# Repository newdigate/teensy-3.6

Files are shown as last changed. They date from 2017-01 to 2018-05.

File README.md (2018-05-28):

# Teensy 3.6 audio display projects

I'd like to explore whats possible with a teensy 3.6, the sgtl5000 audioboard, and an ILI9341 tft display board;
* https://www.pjrc.com/teensy/index.html
* https://www.pjrc.com/store/teensy3_audio.html
* https://www.pjrc.com/store/display_ili9341.html

I have a little bit of electrical engineering knowledge but I don't have alot of practical experience. I am a software engineer by trade and Im interested in audio applications of the teensy devices; 

I've wired the three components together using breadboard and jumper wires. Although it does work intermittently, the digital i2s audio connection is very fragile and mostly results in heavy digital distorion. I've tried to rule out all the obvious potential faults - swapped teensy mainboards, swapped audioboards, swapped different versions of teensy devices... the problem seems to be with my breadboard, or the jumper wires. I need to check it out with a decent oscilliscope. So I've decided to build a custom PCB. I think this should solve my distortion issue.    

[some things I learned about Fritzing](https://github.com/newdigate/teensy-3.6/tree/master/fritzing)

### About Teensy:
Teensy is an awesome microcontroller development kit from pjrc.com http://www.pjrc.com/teensy/index.html

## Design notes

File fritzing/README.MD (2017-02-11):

### Some things I learned about Fritzing
A few months ago I started noticing some really nice diagrams (mostly arduino) while searching for pull-up resistor solutions for arduino. I was curious about how people were creating these nice breadboard diagrams (I love a diagram). I discovered Fritzing this way. 

When I started this project a week or two ago, I thought it would be good to use Fritzing to build the PCB, since the custom parts for previous teensy models already exist in fritzing. My first step was to build svg files for breadboard view, schematic view and pcb view for fritzing. This was my first pcb project, ever. 

Now that I've made a couple of iterations of my first custom fritzing part, I've learned a few things. 
  * Fritzing makes really nice visual diagrams of breadboards.
  * It has a decent collection of components.
  * It is a great platform for teachers, students and enthusiasts. 
  * Making a custom parts for the first time is pretty tough. But all the information is out there.  
  * When creating custom parts, it crashes (esp. when you're learning fritzing svg integration). Work must be saved frequently;    
  * The documentation on making custom parts is a little out dated.
  * Autorouting is not usable (schematic, or pcb).
  * It is not practical to build a PCB in fritzing. Unfortunately. 
  
Having learnt these things I am glad there is a teensy 3.6 component for fritzing.

I have also decided to go forward using Eagle to create PCBs and Fritzing to create sweet breadboard diagrams. 

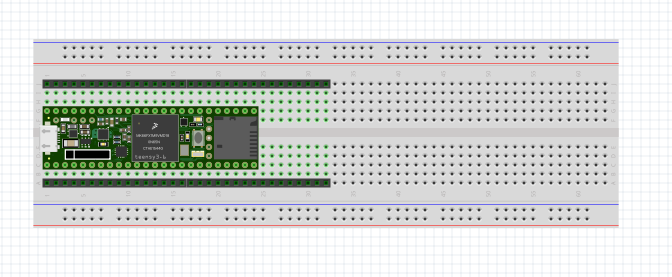
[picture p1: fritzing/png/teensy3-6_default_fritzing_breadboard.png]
teensy breadboard view teensy 3.6 pcb for fritzing


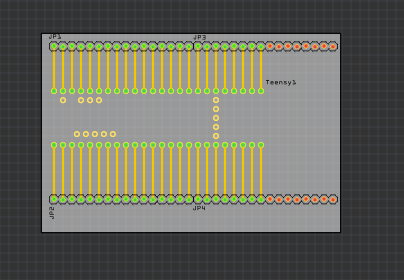
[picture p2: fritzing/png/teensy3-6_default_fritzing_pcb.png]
teensy pcb view teensy 3.6 pcb for fritzing


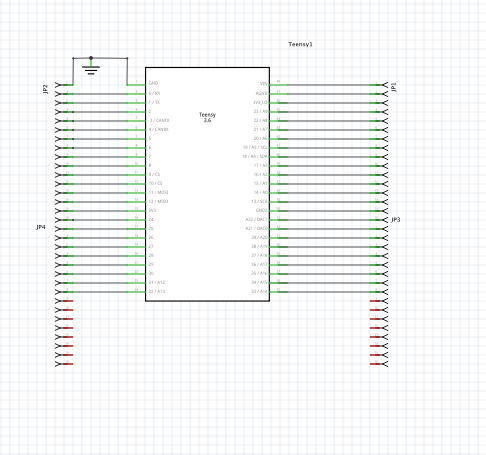
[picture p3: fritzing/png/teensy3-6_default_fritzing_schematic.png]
teensy schematic view teensy 3.6 pcb for fritzing


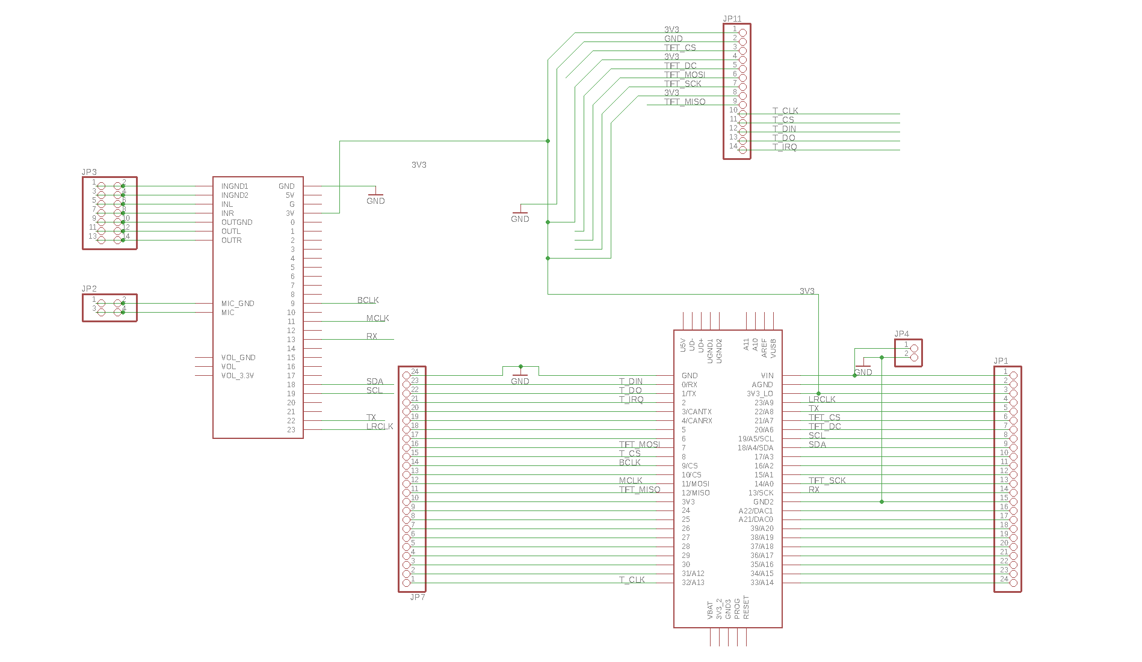
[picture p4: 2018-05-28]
audio-board-tft/images/teensy-3.6-audio-tft.png

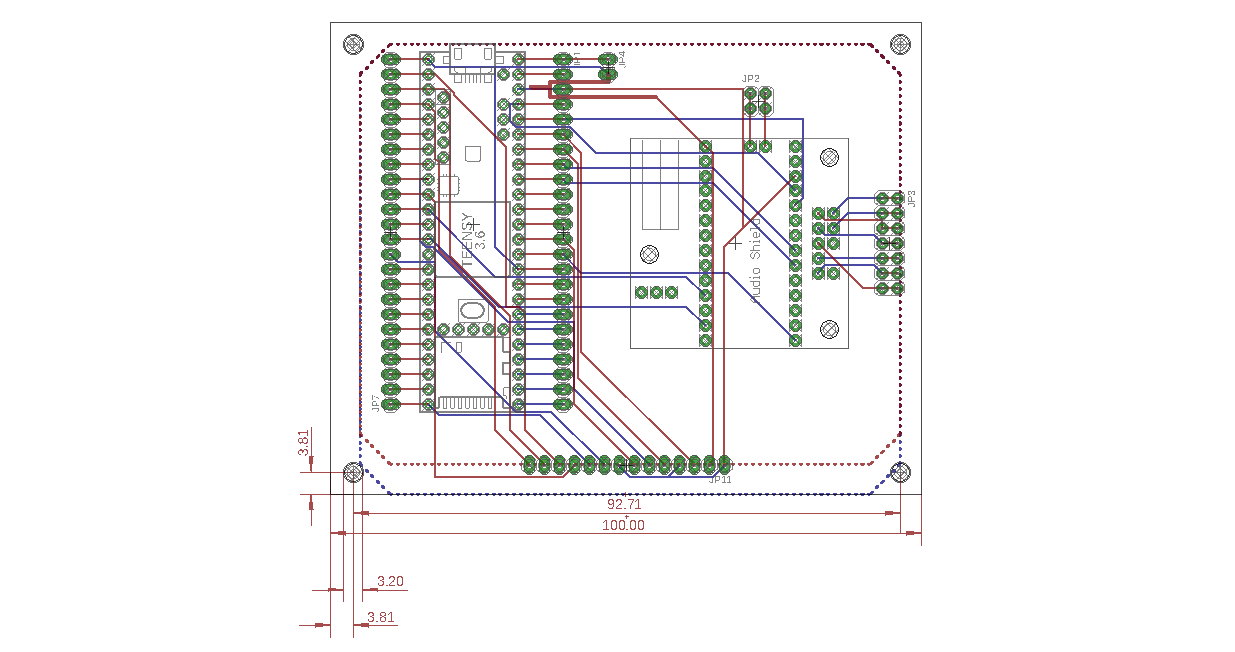
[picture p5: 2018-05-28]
audio-board-tft/images/teensy-3.6-audio-tft-pcb.png

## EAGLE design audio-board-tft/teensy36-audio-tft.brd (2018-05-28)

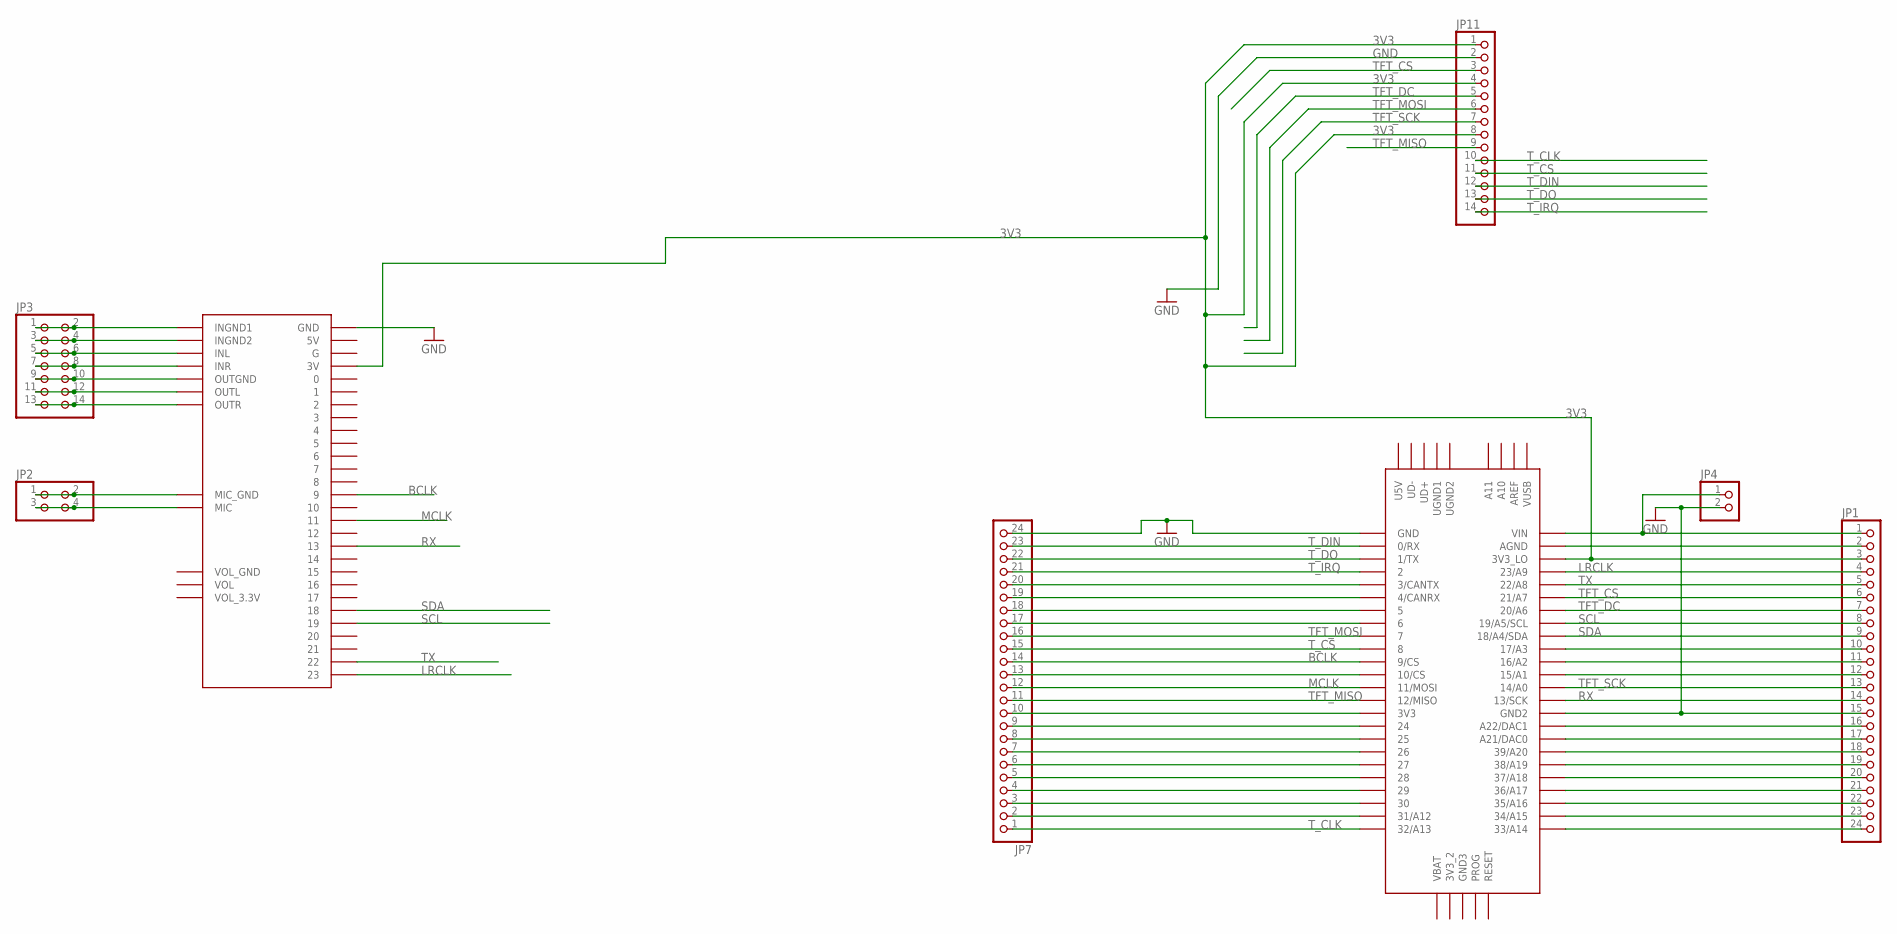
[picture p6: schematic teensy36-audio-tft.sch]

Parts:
JP1, JP7: PINHD-1X24; 1X24
JP2: PINHD-2X2; 2X02
JP3: PINHD-2X7; 2X07
JP4: PINHD-1X2; 1X02
JP11: PINHD-1X14; 1X14
U$2: AUDIOSHIELD
U$3: TEENSY_3.5/3.6

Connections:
3V3: JP1.3, JP11.1, JP11.4, JP11.8, U$2.3V, U$3.3V3_LO
BCLK: JP7.14, U$2.9, U$3.9/CS
GND: JP1.15, JP4.2, JP7.24, JP11.2, U$2.GND, U$3.GND, U$3.GND2
LRCLK: JP1.4, U$2.23, U$3.23/A9
MCLK: JP7.12, U$2.11, U$3.11/MOSI
unnamed: JP2.1, JP2.2, U$2.GND_MIC (MIC_GND)
unnamed: JP1.1, JP4.1, U$3.VIN
unnamed: JP7.20, U$3.3/CANTX
unnamed: JP7.19, U$3.4/CANRX
unnamed: JP7.18, U$3.5
unnamed: JP2.3, JP2.4, U$2.MIC
unnamed: JP3.1, JP3.2, U$2.INGND1
unnamed: JP3.3, JP3.4, U$2.INGND2
unnamed: JP3.5, JP3.6, U$2.INL
unnamed: JP3.7, JP3.8, U$2.INR
unnamed: JP3.9, JP3.10, U$2.OUTGND
unnamed: JP3.11, JP3.12, U$2.OUTL
unnamed: JP3.13, JP3.14, U$2.OUTR
unnamed: JP7.17, U$3.6
unnamed: JP7.13, U$3.10/CS
unnamed: JP7.10, U$3.3V3
unnamed: JP7.9, U$3.24
unnamed: JP7.8, U$3.25
unnamed: JP7.7, U$3.26
unnamed: JP7.6, U$3.27
unnamed: JP7.5, U$3.28
unnamed: JP7.4, U$3.29
unnamed: JP7.3, U$3.30
unnamed: JP7.2, U$3.31/A12
unnamed: JP1.2, U$3.AGND
unnamed: JP1.10, U$3.17/A3
unnamed: JP1.11, U$3.16/A2
unnamed: JP1.12, U$3.15/A1
unnamed: JP1.16, U$3.A22/DAC1
unnamed: JP1.17, U$3.21/DAC0 (A21/DAC0)
unnamed: JP1.18, U$3.39/A20
unnamed: JP1.19, U$3.38/A19
unnamed: JP1.20, U$3.37/A18
unnamed: JP1.21, U$3.36/A17
unnamed: JP1.22, U$3.35/A16
unnamed: JP1.23, U$3.34/A15
unnamed: JP1.24, U$3.33/A14
RX: JP1.14, U$2.13, U$3.13/SCK
SCL: JP1.8, U$2.19, U$3.19/A5/SCL
SDA: JP1.9, U$2.18, U$3.18/A4/SDA
TFT_CS: JP1.6, JP11.3, U$3.21/A7
TFT_DC: JP1.7, JP11.5, U$3.20/A6
TFT_MISO: JP7.11, JP11.9
TFT_MOSI: JP7.16, JP11.6, U$3.7
TFT_SCK: JP1.13, JP11.7, U$3.14/A0
TX: JP1.5, U$2.22, U$3.22/A8
T_CLK: JP7.1, JP11.10, U$3.32/A13
T_CS: JP7.15, JP11.11, U$3.8
T_DIN: JP7.23, JP11.12, U$3.0/RX
T_DO: JP7.22, JP11.13, U$3.1/TX
T_IRQ: JP7.21, JP11.14, U$3.2

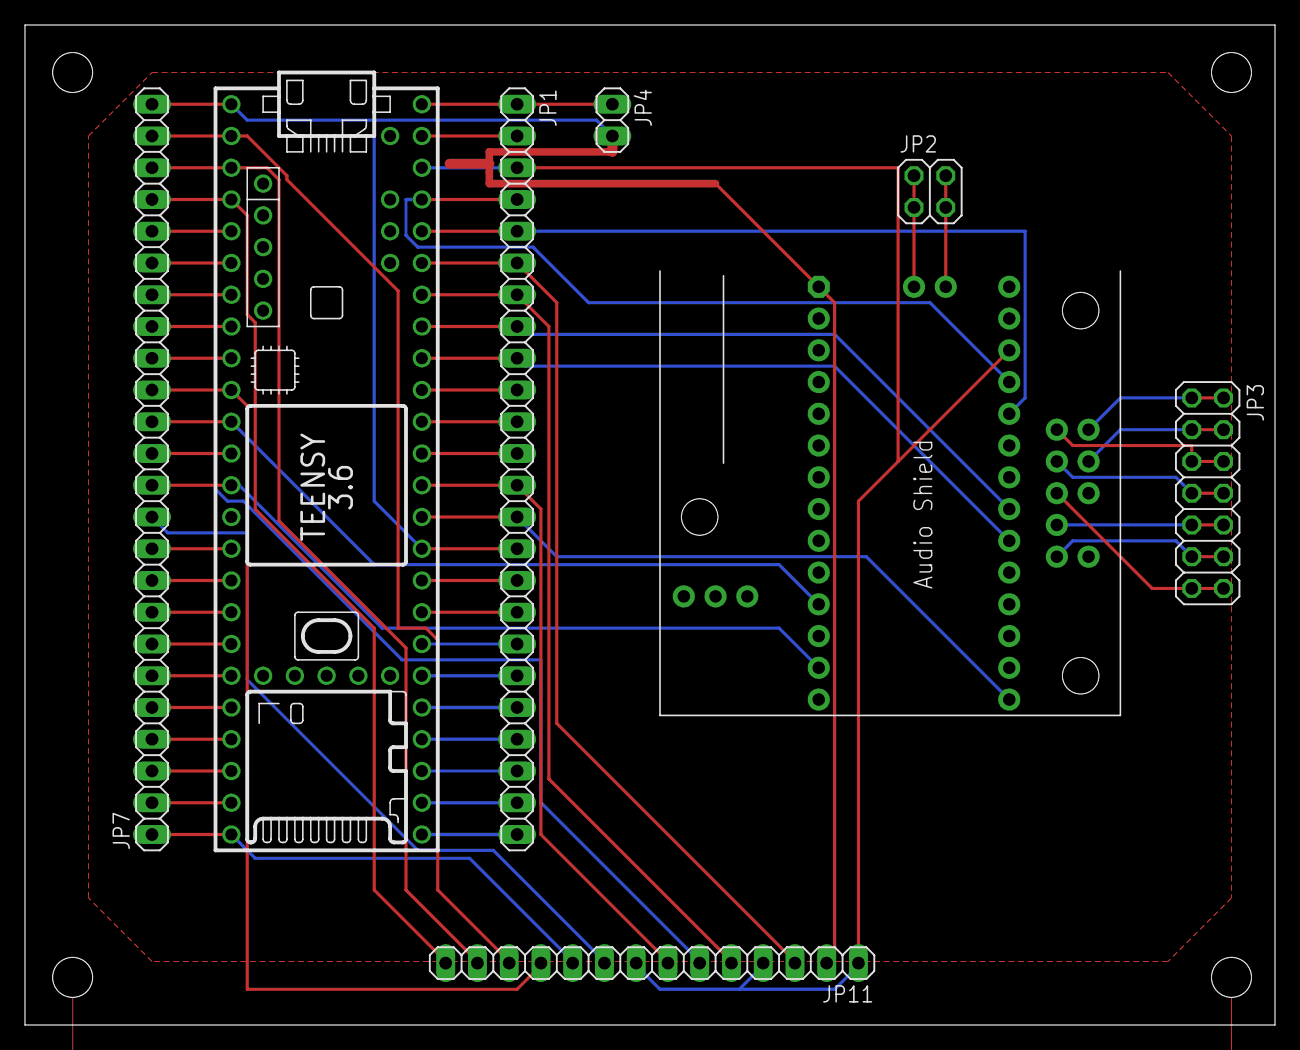
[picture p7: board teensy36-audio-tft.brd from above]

Board: 2 copper layers, 100.0 x 80.0 mm, 8 parts (0 on the bottom side), 56 nets.

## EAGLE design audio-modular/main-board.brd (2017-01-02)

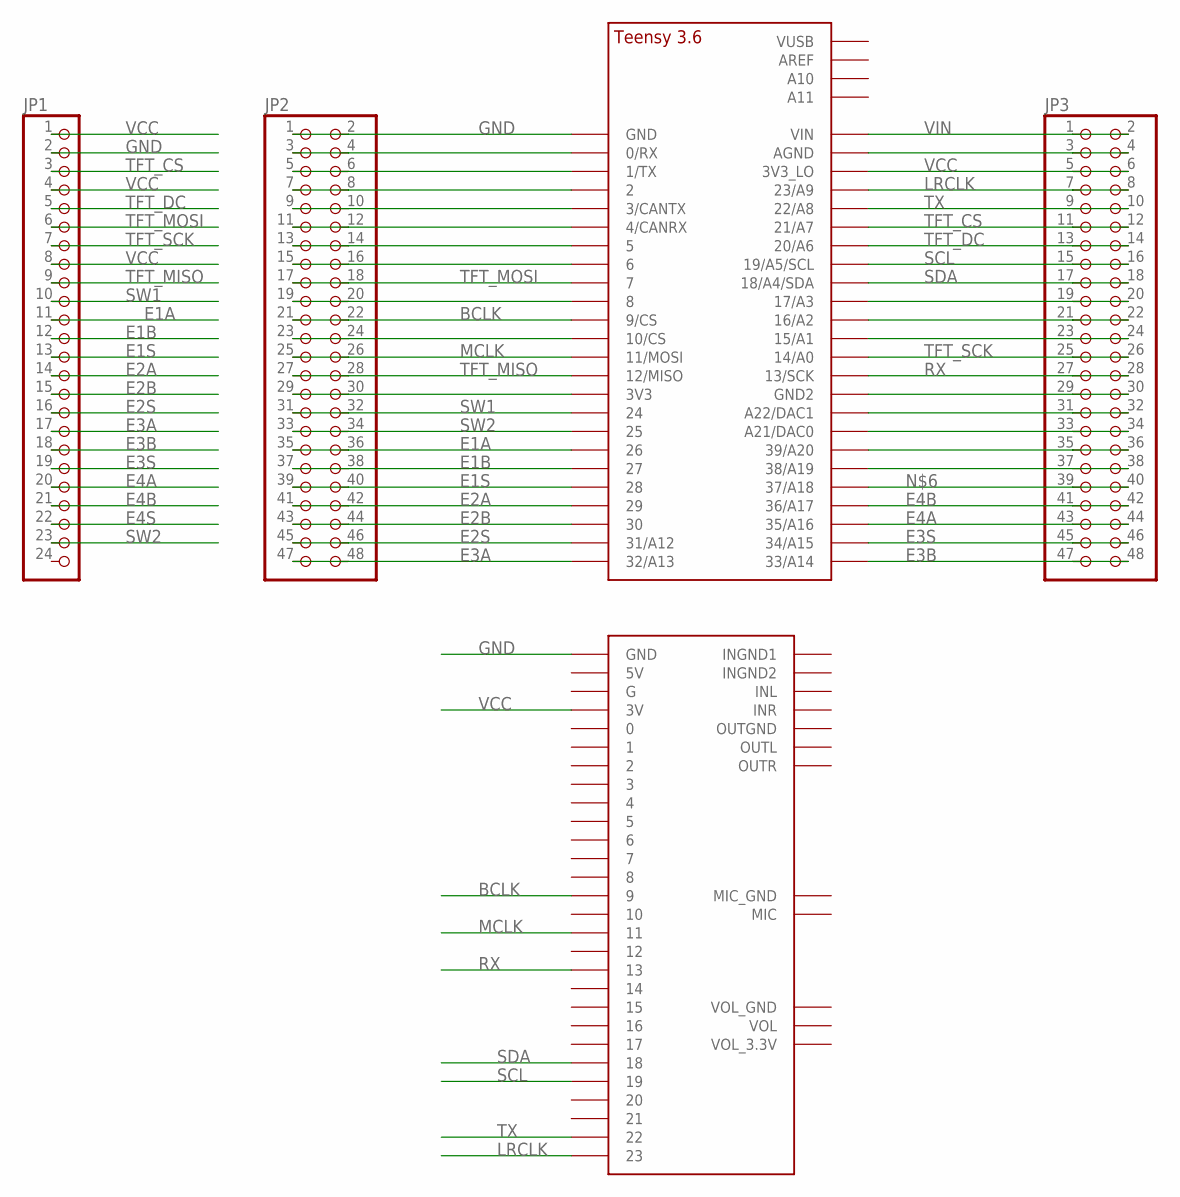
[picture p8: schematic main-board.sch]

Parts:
JP1: PINHD-1X24; 1X24
JP2, JP3: PINHD-2X24; 2X24
U$1: TEENSY_3.5/3.6_BASIC
U$2: AUDIOSHIELD

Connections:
BCLK: JP2.21, JP2.22, U$1.9/CS, U$2.9
E1A: JP1.11, JP2.35, JP2.36, U$1.26
E1B: JP1.12, JP2.37, JP2.38, U$1.27
E1S: JP1.13, JP2.39, JP2.40, U$1.28
E2A: JP1.14, JP2.41, JP2.42, U$1.29
E2B: JP1.15, JP2.43, JP2.44, U$1.30
E2S: JP1.16, JP2.45, JP2.46, U$1.31/A12
E3A: JP1.17, JP2.47, JP2.48, U$1.32/A13
E3B: JP1.18, JP3.47, JP3.48, U$1.33/A14
E3S: JP1.19, JP3.45, JP3.46, U$1.34/A15
E4A: JP1.20, JP3.43, JP3.44, U$1.35/A16
E4B: JP1.21, JP3.41, JP3.42, U$1.36/A17
E4S: JP1.22
GND: JP1.2, JP2.1, JP2.2, U$1.GND, U$2.GND
LRCLK: JP3.7, JP3.8, U$1.23/A9, U$2.23
MCLK: JP2.25, JP2.26, U$1.11/MOSI, U$2.11
unnamed: JP2.3, JP2.4, U$1.0/RX
unnamed: JP2.5, JP2.6, U$1.1/TX
unnamed: JP2.7, JP2.8, U$1.2
unnamed: JP3.39, JP3.40, U$1.37/A18
unnamed: JP2.9, JP2.10, U$1.3/CANTX
unnamed: JP2.11, JP2.12, U$1.4/CANRX
unnamed: JP2.13, JP2.14, U$1.5
unnamed: JP2.15, JP2.16, U$1.6
unnamed: JP2.19, JP2.20, U$1.8
unnamed: JP2.23, JP2.24, U$1.10/CS
unnamed: JP2.29, JP2.30, U$1.3V3
unnamed: JP3.3, JP3.4, U$1.AGND
unnamed: JP3.19, JP3.20, U$1.17/A3
unnamed: JP3.21, JP3.22, U$1.16/A2
unnamed: JP3.23, JP3.24, U$1.15/A1
unnamed: JP3.29, JP3.30, U$1.GND2
unnamed: JP3.31, JP3.32, U$1.A22/DAC1
unnamed: JP3.33, JP3.34, U$1.21/DAC0 (A21/DAC0)
unnamed: JP3.35, JP3.36, U$1.39/A20
unnamed: JP3.37, JP3.38, U$1.38/A19
RX: JP3.27, JP3.28, U$1.13/SCK, U$2.13
SCL: JP3.15, JP3.16, U$1.19/A5/SCL, U$2.19
SDA: JP3.17, JP3.18, U$1.18/A4/SDA, U$2.18
SW1: JP1.10, JP2.31, JP2.32, U$1.24
SW2: JP1.23, JP2.33, JP2.34, U$1.25
TFT_CS: JP1.3, JP3.11, JP3.12, U$1.21/A7
TFT_DC: JP1.5, JP3.13, JP3.14, U$1.20/A6
TFT_MISO: JP1.9, JP2.27, JP2.28, U$1.12/MISO
TFT_MOSI: JP1.6, JP2.17, JP2.18, U$1.7
TFT_SCK: JP1.7, JP3.25, JP3.26, U$1.14/A0
TX: JP3.9, JP3.10, U$1.22/A8, U$2.22
VCC: JP1.1, JP1.4, JP1.8, JP3.5, JP3.6, U$1.3V3_LO, U$2.3V
VIN: JP3.1, JP3.2, U$1.VIN

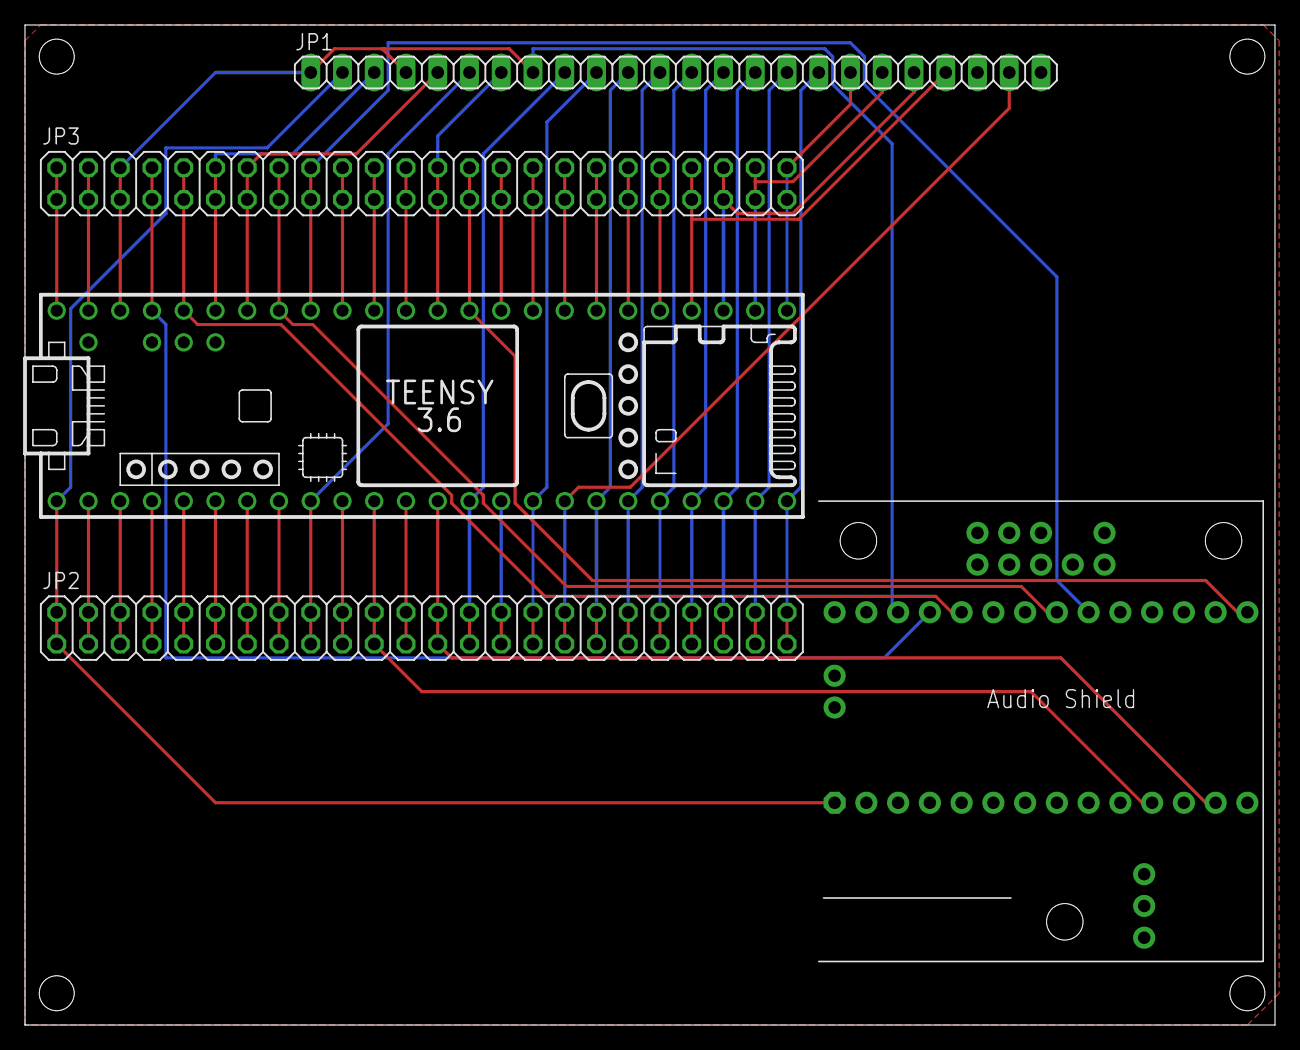
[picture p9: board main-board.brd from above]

Board: 2 copper layers, 100.0 x 80.0 mm, 5 parts (0 on the bottom side), 48 nets.

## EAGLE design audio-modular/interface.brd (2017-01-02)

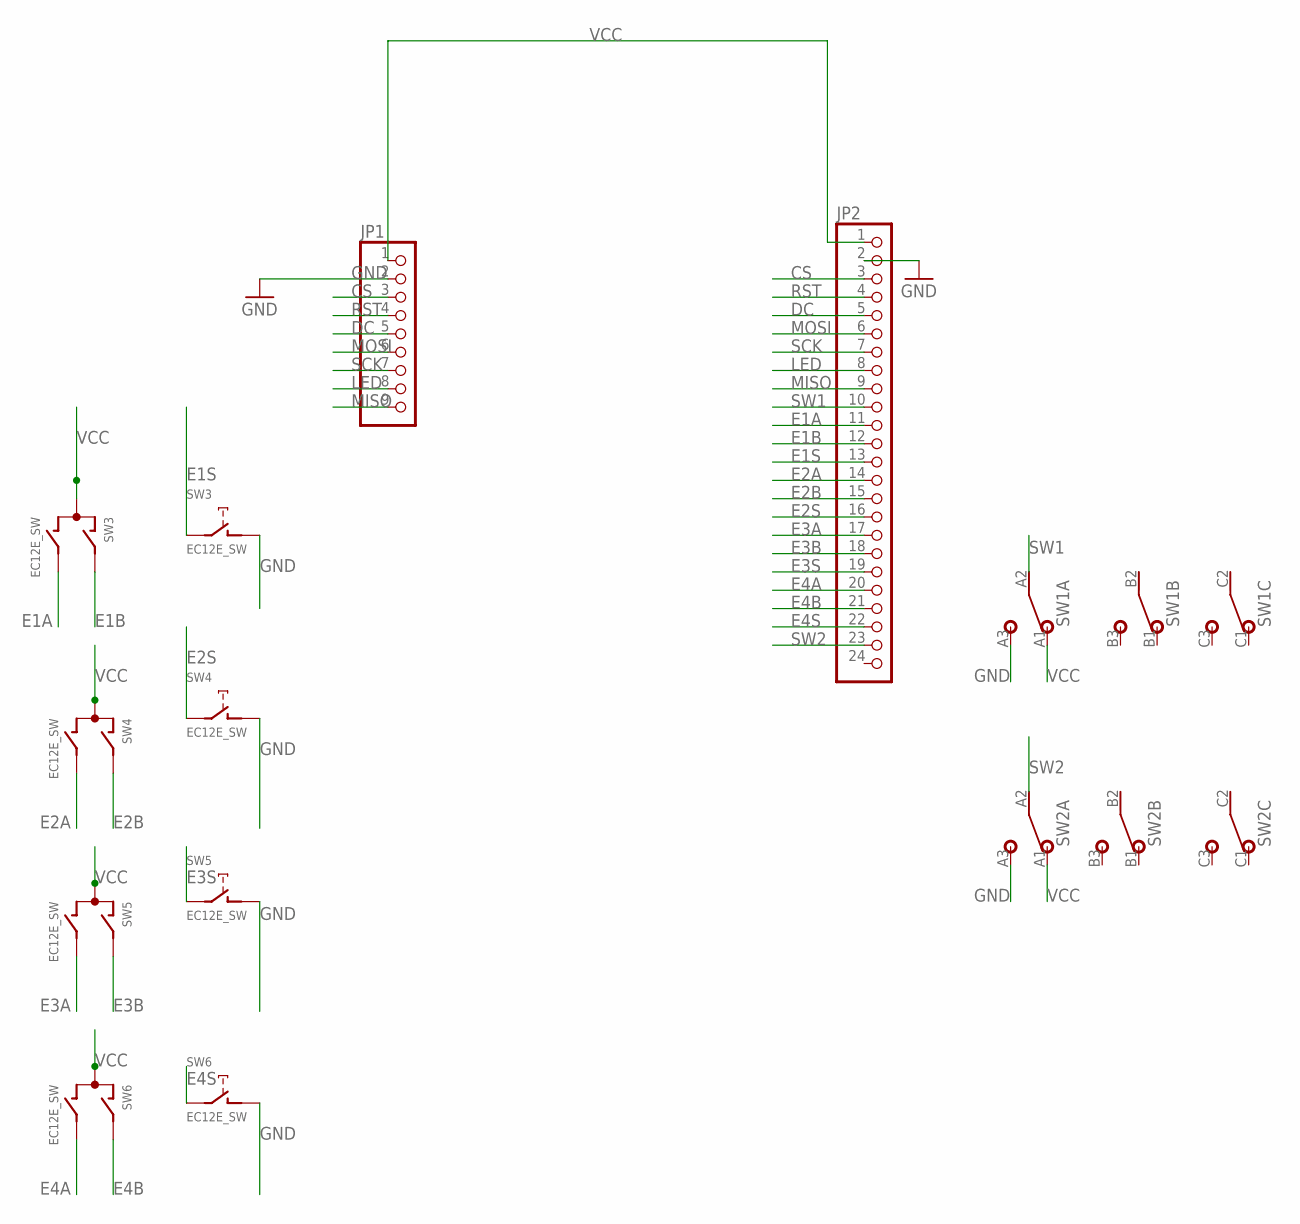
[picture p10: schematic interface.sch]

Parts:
JP1: PINHD-1X9; 1X09
JP2: PINHD-1X24; 1X24
SW1, SW2: 3PDTBLUE; CHINABLUE
SW3, SW4, SW5, SW6: EC12E_SW; ALPS_EC12E_SW

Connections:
CS: JP1.3, JP2.3
DC: JP1.5, JP2.5
E1A: JP2.11, SW3.B
E1B: JP2.12, SW3.A
E1S: JP2.13, SW3.E (2)
E2A: JP2.14, SW4.B
E2B: JP2.15, SW4.A
E2S: JP2.16, SW4.E (2)
E3A: JP2.17, SW5.B
E3B: JP2.18, SW5.A
E3S: JP2.19, SW5.E (2)
E4A: JP2.20, SW6.B
E4B: JP2.21, SW6.A
E4S: JP2.22, SW6.E (2)
GND: JP1.2, JP2.2, SW1.A3 (3), SW2.A3 (3), SW3.D (1), SW4.D (1), SW5.D (1), SW6.D (1)
LED: JP1.8, JP2.8
MISO: JP1.9, JP2.9
MOSI: JP1.6, JP2.6
RST: JP1.4, JP2.4
SCK: JP1.7, JP2.7
SW1: JP2.10, SW1.A2 (2)
SW2: JP2.23, SW2.A2 (2)
VCC: JP1.1, JP2.1, SW1.A1 (1), SW2.A1 (1), SW3.C, SW4.C, SW5.C, SW6.C

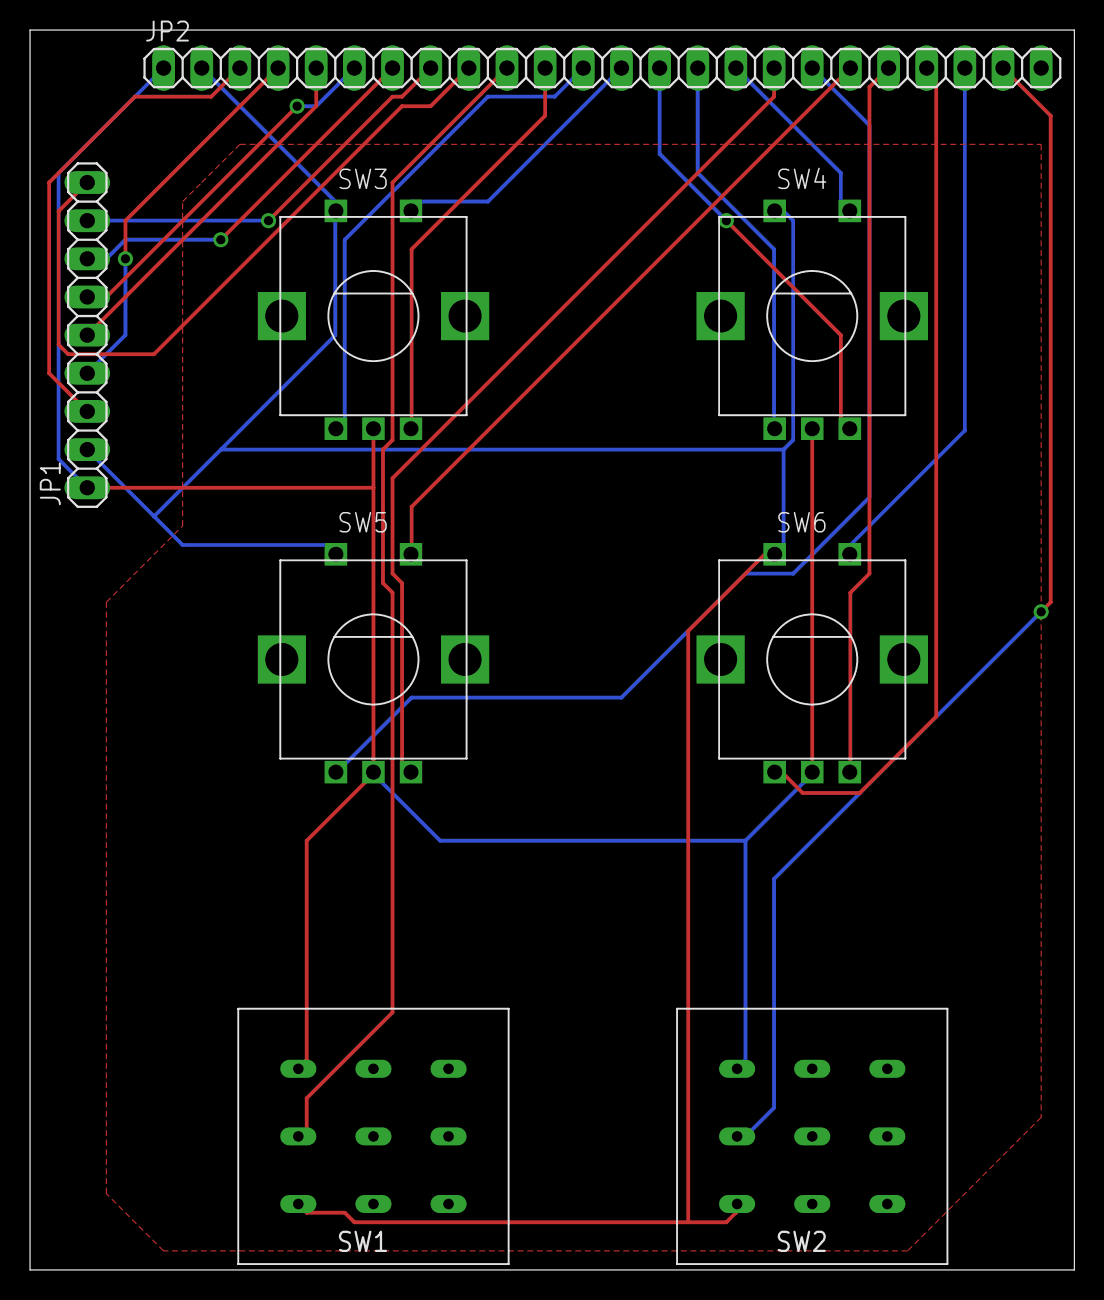
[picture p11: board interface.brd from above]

Board: 2 copper layers, 69.5 x 82.5 mm, 8 parts (0 on the bottom side), 23 nets.

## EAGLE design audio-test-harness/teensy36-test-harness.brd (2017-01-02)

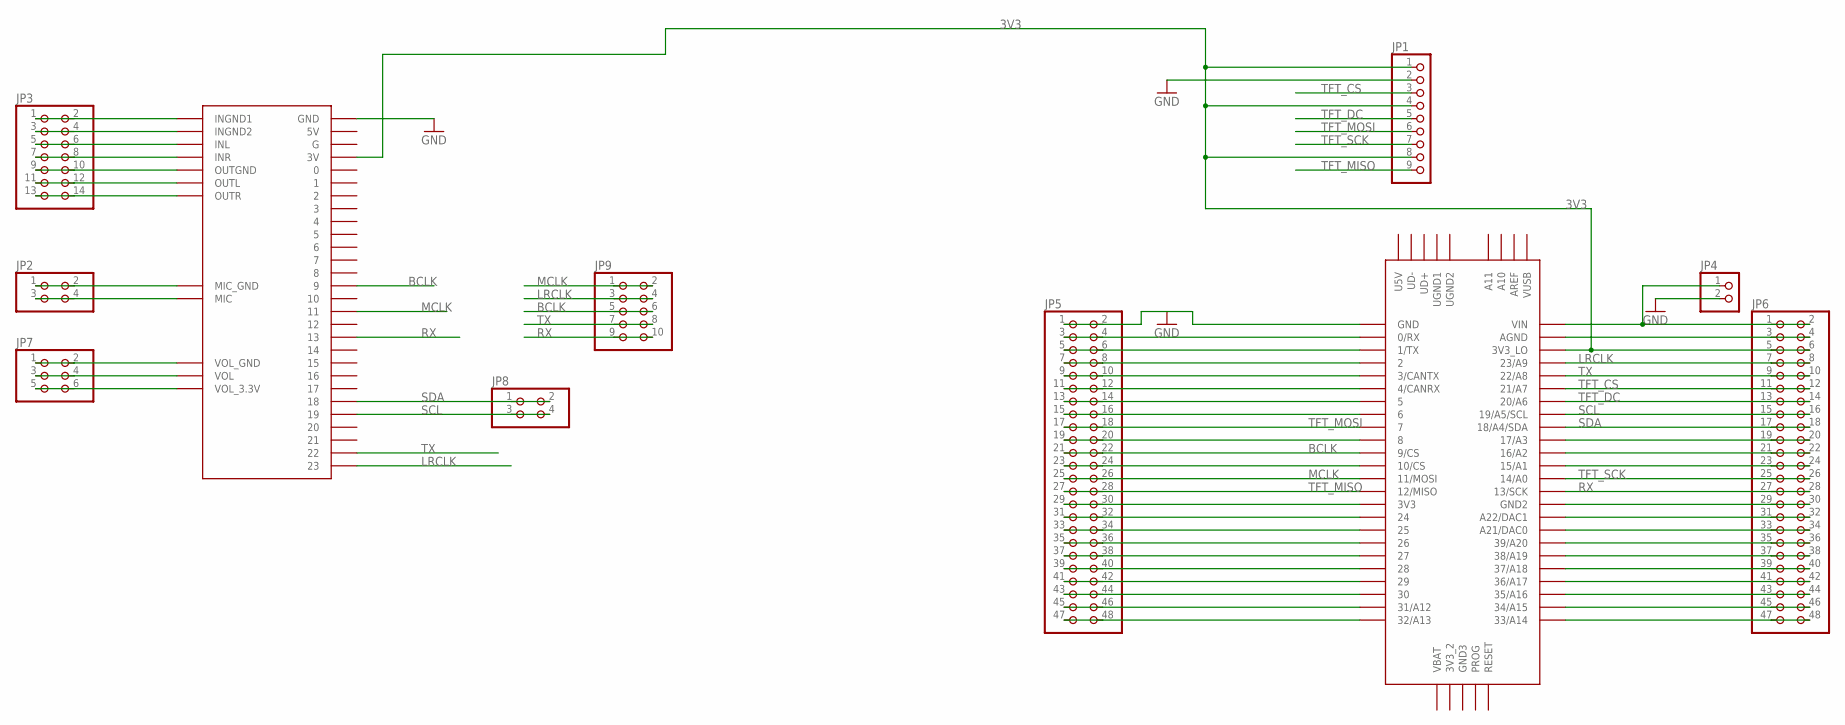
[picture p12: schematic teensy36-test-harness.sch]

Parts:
JP1: PINHD-1X9; 1X09
JP2, JP8: PINHD-2X2; 2X02
JP3: PINHD-2X7; 2X07
JP4: PINHD-1X2; 1X02
JP5, JP6: PINHD-2X24; 2X24
JP7: PINHD-2X3; 2X03
JP9: PINHD-2X5; 2X05
U$2: AUDIOSHIELD
U$3: TEENSY_3.5/3.6

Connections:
3V3: JP1.1, JP1.4, JP1.8, JP6.5, JP6.6, U$2.3V, U$3.3V3_LO
BCLK: JP5.21, JP5.22, JP9.5, JP9.6, U$2.9, U$3.9/CS
GND: JP1.2, JP4.2, JP5.1, JP5.2, U$2.GND, U$3.GND
LRCLK: JP6.7, JP6.8, JP9.3, JP9.4, U$2.23, U$3.23/A9
MCLK: JP5.25, JP5.26, JP9.1, JP9.2, U$2.11, U$3.11/MOSI
unnamed: JP2.1, JP2.2, U$2.GND_MIC (MIC_GND)
unnamed: JP4.1, JP6.1, JP6.2, U$3.VIN
unnamed: JP7.1, JP7.2, U$2.VOL_GND
unnamed: JP5.3, JP5.4, U$3.0/RX
unnamed: JP5.5, JP5.6, U$3.1/TX
unnamed: JP5.7, JP5.8, U$3.2
unnamed: JP5.9, JP5.10, U$3.3/CANTX
unnamed: JP5.11, JP5.12, U$3.4/CANRX
unnamed: JP5.13, JP5.14, U$3.5
unnamed: JP2.3, JP2.4, U$2.MIC
unnamed: JP3.1, JP3.2, U$2.INGND1
unnamed: JP3.3, JP3.4, U$2.INGND2
unnamed: JP3.5, JP3.6, U$2.INL
unnamed: JP3.7, JP3.8, U$2.INR
unnamed: JP3.9, JP3.10, U$2.OUTGND
unnamed: JP3.11, JP3.12, U$2.OUTL
unnamed: JP3.13, JP3.14, U$2.OUTR
unnamed: JP5.15, JP5.16, U$3.6
unnamed: JP7.3, JP7.4, U$2.VOL
unnamed: JP5.19, JP5.20, U$3.8
unnamed: JP7.5, JP7.6, U$2.VOL_3.3V
unnamed: JP5.23, JP5.24, U$3.10/CS
unnamed: JP5.29, JP5.30, U$3.3V3
unnamed: JP5.31, JP5.32, U$3.24
unnamed: JP5.33, JP5.34, U$3.25
unnamed: JP5.35, JP5.36, U$3.26
unnamed: JP5.37, JP5.38, U$3.27
unnamed: JP5.39, JP5.40, U$3.28
unnamed: JP5.41, JP5.42, U$3.29
unnamed: JP5.43, JP5.44, U$3.30
unnamed: JP5.45, JP5.46, U$3.31/A12
unnamed: JP5.47, JP5.48, U$3.32/A13
unnamed: JP6.3, JP6.4, U$3.AGND
unnamed: JP6.19, JP6.20, U$3.17/A3
unnamed: JP6.21, JP6.22, U$3.16/A2
unnamed: JP6.23, JP6.24, U$3.15/A1
unnamed: JP6.29, JP6.30, U$3.GND2
unnamed: JP6.31, JP6.32, U$3.A22/DAC1
unnamed: JP6.33, JP6.34, U$3.21/DAC0 (A21/DAC0)
unnamed: JP6.35, JP6.36, U$3.39/A20
unnamed: JP6.37, JP6.38, U$3.38/A19
unnamed: JP6.39, JP6.40, U$3.37/A18
unnamed: JP6.41, JP6.42, U$3.36/A17
unnamed: JP6.43, JP6.44, U$3.35/A16
unnamed: JP6.45, JP6.46, U$3.34/A15
unnamed: JP6.47, JP6.48, U$3.33/A14
RX: JP6.27, JP6.28, JP9.9, JP9.10, U$2.13, U$3.13/SCK
SCL: JP6.15, JP6.16, JP8.3, JP8.4, U$2.19, U$3.19/A5/SCL
SDA: JP6.17, JP6.18, JP8.1, JP8.2, U$2.18, U$3.18/A4/SDA
TFT_CS: JP1.3, JP6.11, JP6.12, U$3.21/A7
TFT_DC: JP1.5, JP6.13, JP6.14, U$3.20/A6
TFT_MISO: JP1.9, JP5.27, JP5.28
TFT_MOSI: JP1.6, JP5.17, JP5.18, U$3.7
TFT_SCK: JP1.7, JP6.25, JP6.26, U$3.14/A0
TX: JP6.9, JP6.10, JP9.7, JP9.8, U$2.22, U$3.22/A8

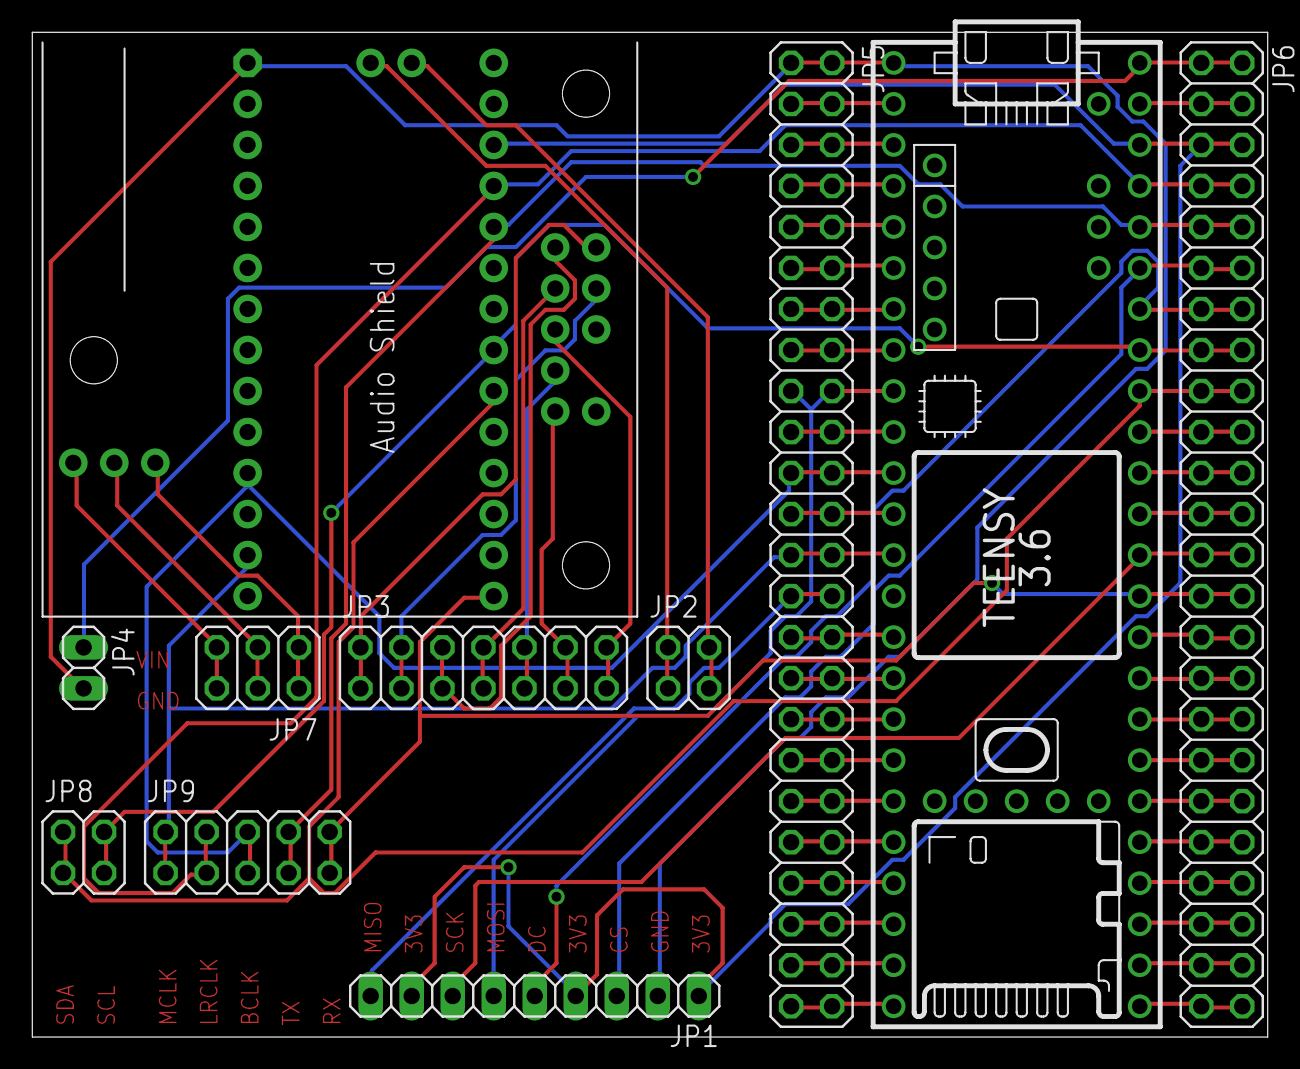
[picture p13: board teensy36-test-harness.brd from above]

Board: 2 copper layers, 76.5 x 62.2 mm, 11 parts (0 on the bottom side), 60 nets.

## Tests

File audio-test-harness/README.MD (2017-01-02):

Circuit, PCB and sketches for Teensy audio display test harness

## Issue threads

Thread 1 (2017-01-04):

Pins on breadboard

kfrancis, 2017-01-04:
Is it possible to have it hook on the breadboard view directly rather than require wires?

newdigate, 2017-01-04:
Yes, I noticed that the pins don't automatically connect when dropping the teensy onto the breadboard. I am fairly new to Fritzing and assumed this was default behaviour; It would be much better if the connections automatically wired correctly when dropping into the breadboard; I will have to look into this...

newdigate, 2017-01-06:
I think it is because the pins are not "male" pins. I might be inspired to fix this if this repository gets a star.

newdigate, 2017-01-07:
The pins are marked as male now, they auto-connect to the breadboard pins.

Closed 2017-01-07.

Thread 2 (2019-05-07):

Displays wrong size in Fritzing

Lhburch, 2019-05-07:
Spacing from pin 1 to pin 14 is 2.1" S/B 1.3"
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
